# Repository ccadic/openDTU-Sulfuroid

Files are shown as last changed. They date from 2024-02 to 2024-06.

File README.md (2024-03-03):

# openDTU-Sulfuroid

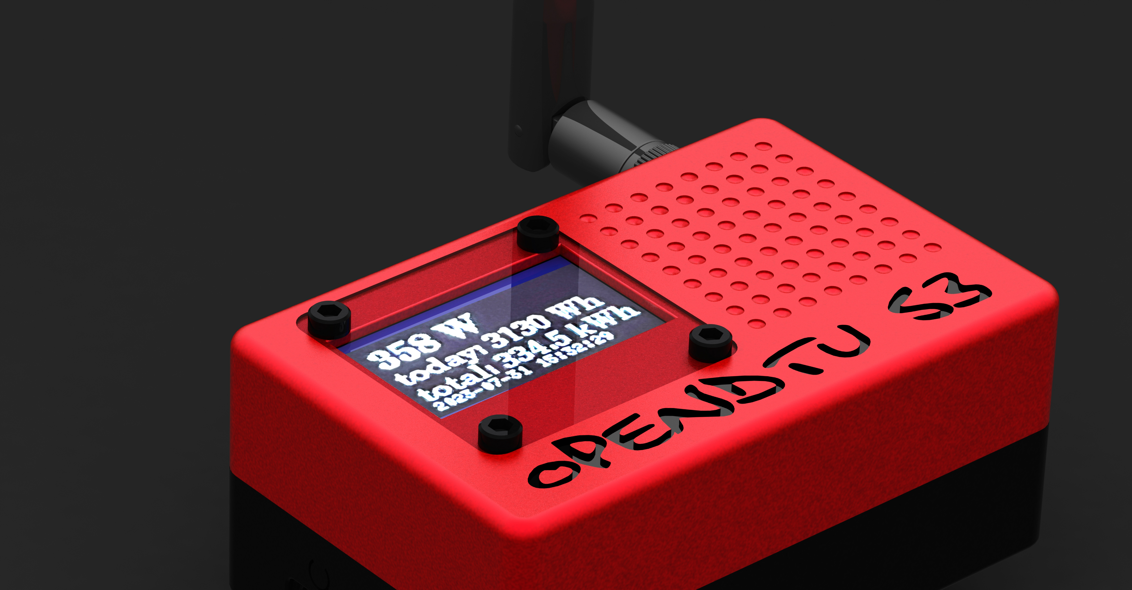
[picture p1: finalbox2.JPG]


Derived from :https://www.opendtu.solar/ 
The pcb is for sale on : https://www.tindie.com/products/electronictrik/esp32s3-opendtu-solar-monitoring-tool/

**Introducing the revolutionary OpenDTU Module: The Future of Solar Energy Management!**

In a world where sustainable energy is not just an option but a necessity, the OpenDTU Module stands as a beacon of innovation and efficiency. Designed with precision and crafted for excellence, this cutting-edge Printed Circuit Board (PCB) is your ultimate gateway to optimizing solar energy production.

The OpenDTU Module revolutionizes the way we interact with solar micro-inverters. Its state-of-the-art design allows for seamless querying of solar micro-inverters, providing you with real-time insights into your energy production. This isn't just about monitoring; it's about maximizing efficiency, reducing costs, and stepping into a future where your solar energy system is smarter and more responsive than ever before.

**Key Features:**

- **Real-Time Monitoring**: Instant access to your energy production data. Watch your energy yield as it happens and make informed decisions on the fly.
- **Universal Compatibility**: Designed to communicate effortlessly with a wide range of solar micro-inverters. The OpenDTU Module speaks the language of your devices.
- **Advanced Analytics**: Not just numbers, but insights. Understand your energy patterns, predict future production, and identify areas for improvement.
- **User-Friendly Interface**: Whether you're a tech wizard or a beginner, the OpenDTU Module offers a simple, intuitive interface for everyone.
- **Robust Design**: Built to last. With its durable components and meticulous design, the OpenDTU Module withstands the test of time and weather.
- **Open Source Freedom**: Unleash the power of community-driven innovation. Customize, enhance, and share your improvements with an ever-growing network of users and developers.
- **Eco-Friendly Operation**: Embrace sustainability not just in energy production but in management too. The OpenDTU Module is designed with eco-conscious materials and processes.

Imagine a world where your solar energy system is not just a part of your home, but a smart, interactive partner in your quest for a sustainable future. The OpenDTU Module brings that world to your doorstep.

Perfect for homeowners, businesses, and solar enthusiasts alike, the OpenDTU Module is more than a PCB; it's a commitment to a brighter, greener planet. Embrace the future of solar energy management today and transform the way you power your world.

Welcome to the era of intelligent solar energy. Welcome to the OpenDTU Module.

Config File for the openDTU PCB

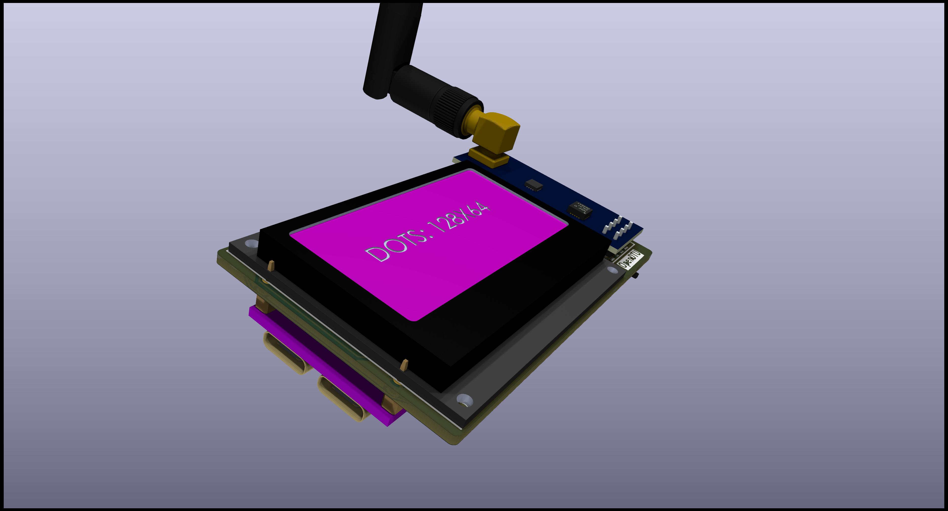
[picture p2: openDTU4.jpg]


Radio modules: https://www.amazon.fr/gp/product/B07VQ838KT/ref=ppx_yo_dt_b_asin_title_o02_s00?ie=UTF8&psc=1
ESP31S3 Long Sev board: https://fr.aliexpress.com/item/1005004642646719.html
Display: https://www.aliexpress.com/item/1005005921902141.html

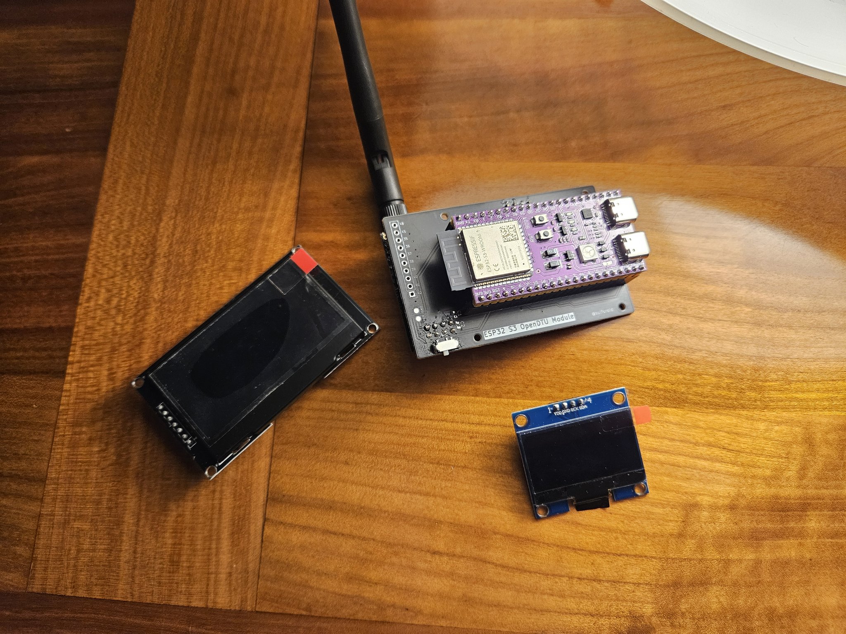
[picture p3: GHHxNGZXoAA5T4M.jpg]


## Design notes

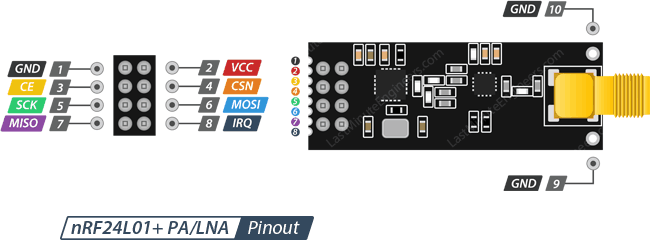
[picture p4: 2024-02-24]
Pinout-nRF24L01-PA-LNA-External-Antenna-Wireless-Transceiver-Module.png

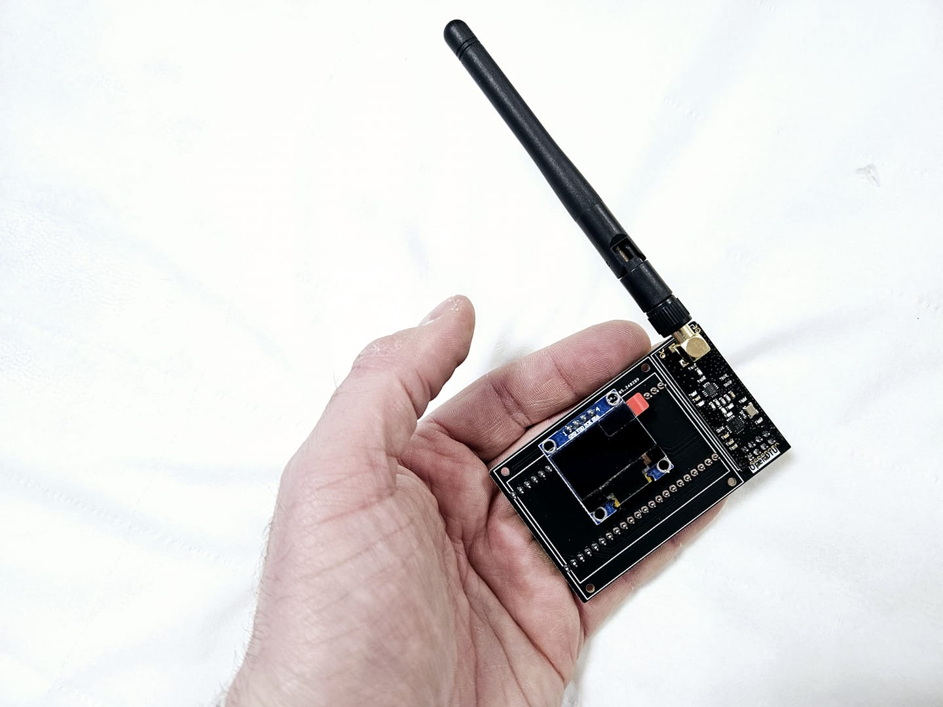
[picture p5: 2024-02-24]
424889018_10231989691474830_318413052973349960_n.jpg

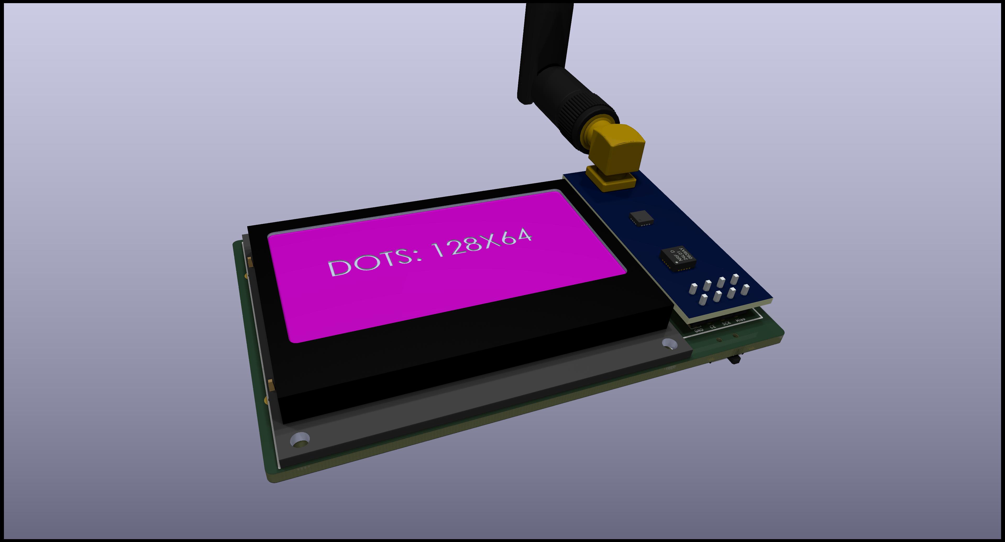
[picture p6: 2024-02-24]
openDTU2.jpg

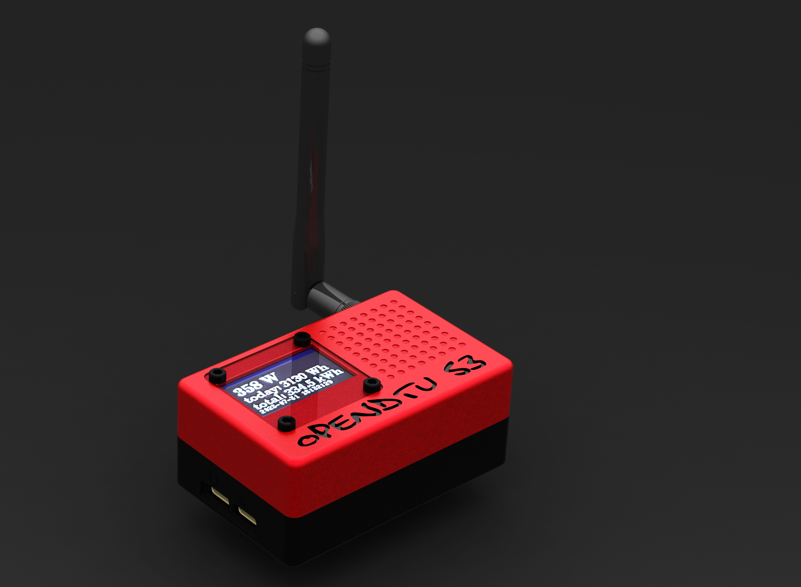
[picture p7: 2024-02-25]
finalbox.JPG

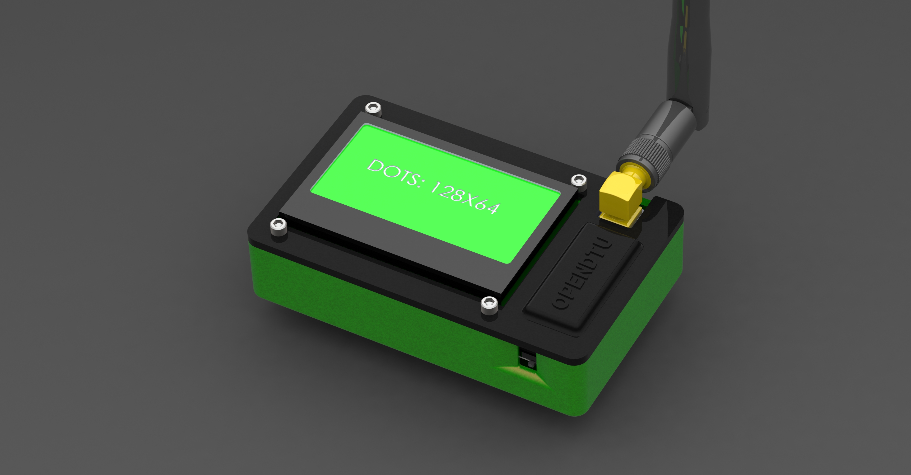
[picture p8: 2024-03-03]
openDTUBIG3.JPG

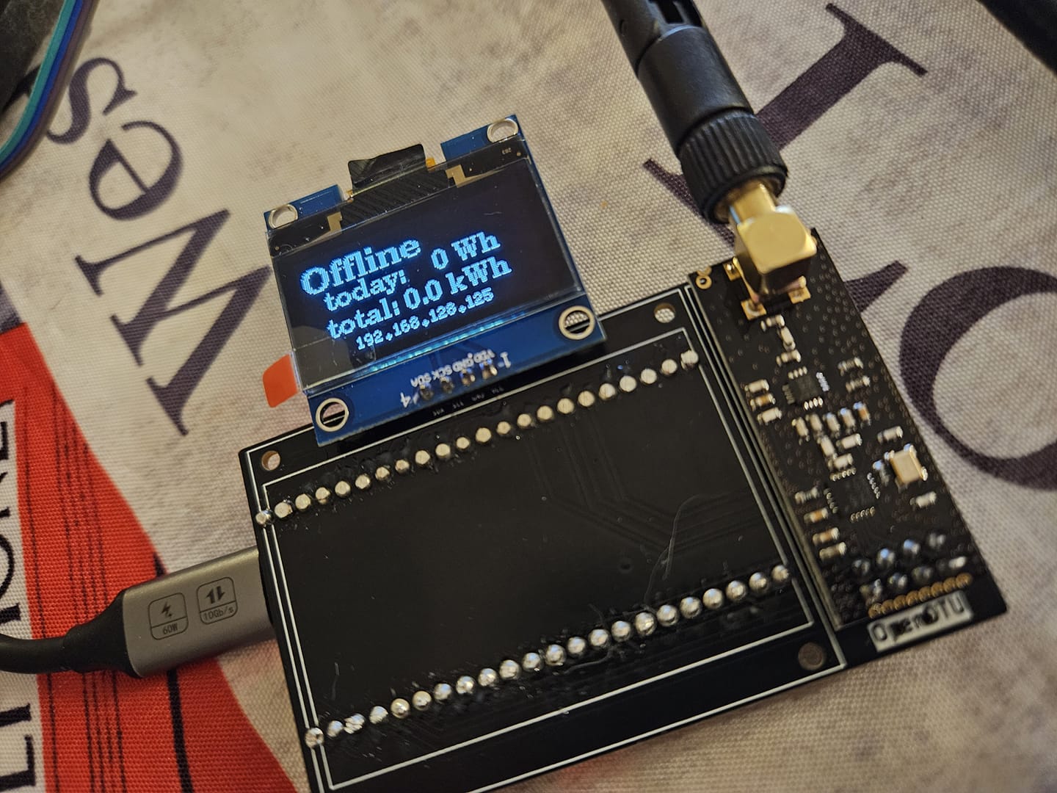
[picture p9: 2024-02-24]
428485526_10231997505990188_1241992412486224182_n.jpg

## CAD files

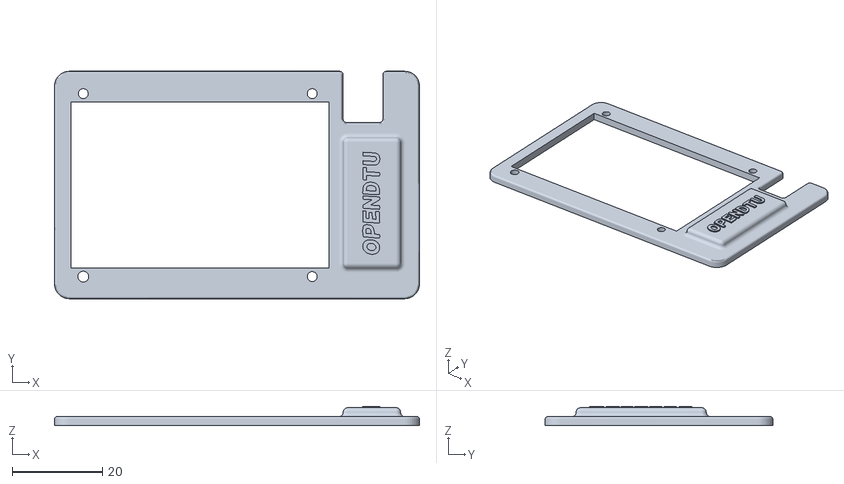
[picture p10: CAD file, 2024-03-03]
3Dfile3/plaqueplexy.STL
81.0 x 50.5 x 4.30

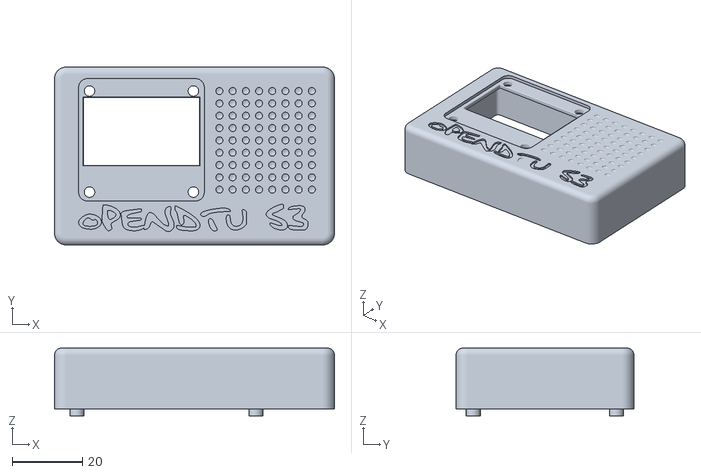
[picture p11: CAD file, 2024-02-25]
3Dfiles/superiorBox.STL
79.5 x 50.5 x 19.3

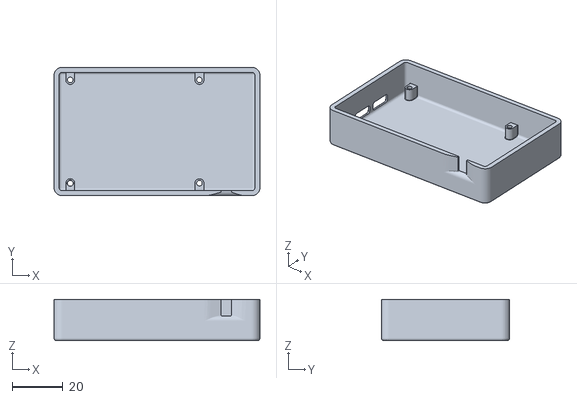
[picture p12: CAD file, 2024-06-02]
3Dfiles2/InferiorBox.STL
81.0 x 50.5 x 16.2

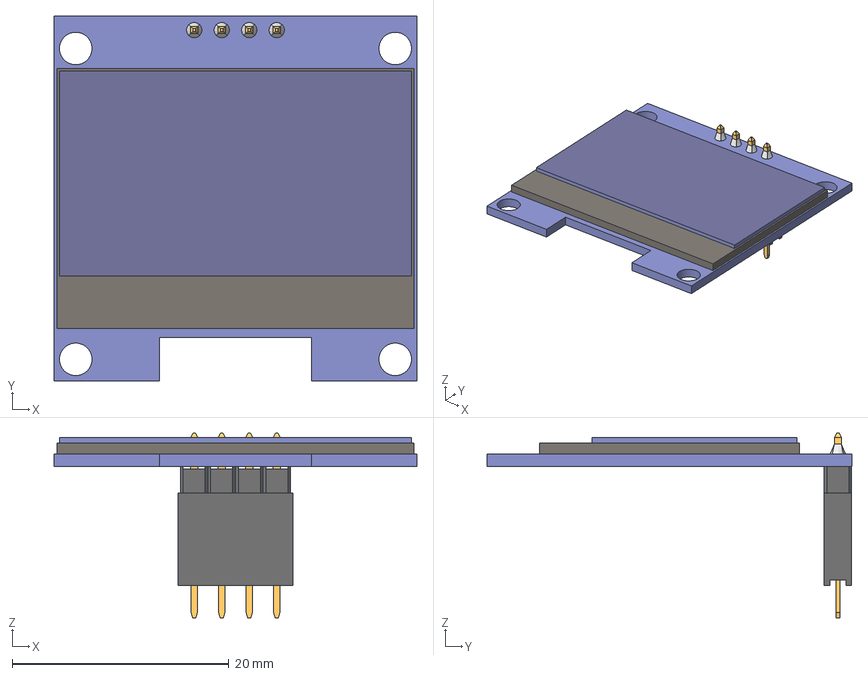
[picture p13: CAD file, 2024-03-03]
OLED I2C 1.3 Inch Display v16.step
33.5 x 33.7 x 17.0 mm
PIN HEADER MALE 2.54MM P4
PIN HEADER FAMALE 2.54MM P4
4 lü Lehim v2

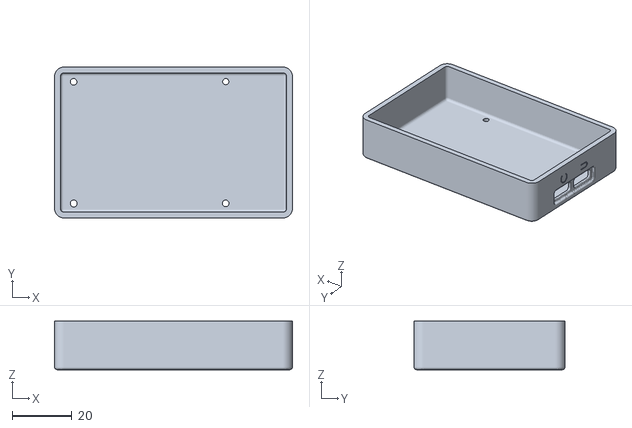
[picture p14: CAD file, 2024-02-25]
3Dfiles/InferiorBox.STL
79.5 x 50.5 x 16.2

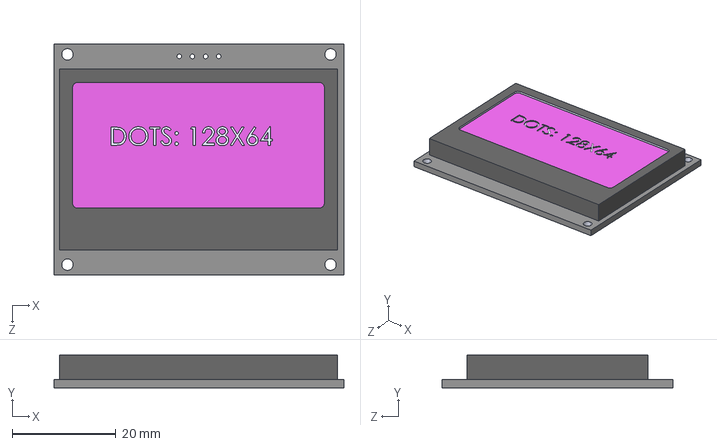
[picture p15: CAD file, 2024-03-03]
LCD-GM12864-59N.STEP
56.0 x 6.30 x 44.6 mm

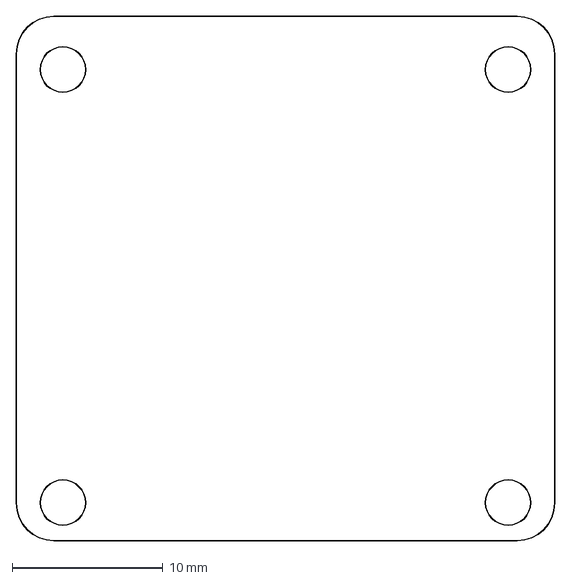
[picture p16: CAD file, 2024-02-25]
3Dfiles/frontglass-laser.DXF
35.7 x 34.8 mm

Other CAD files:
3Dfile3/InferiorBox3.STL
3Dfile3/plaqueplexy.DXF

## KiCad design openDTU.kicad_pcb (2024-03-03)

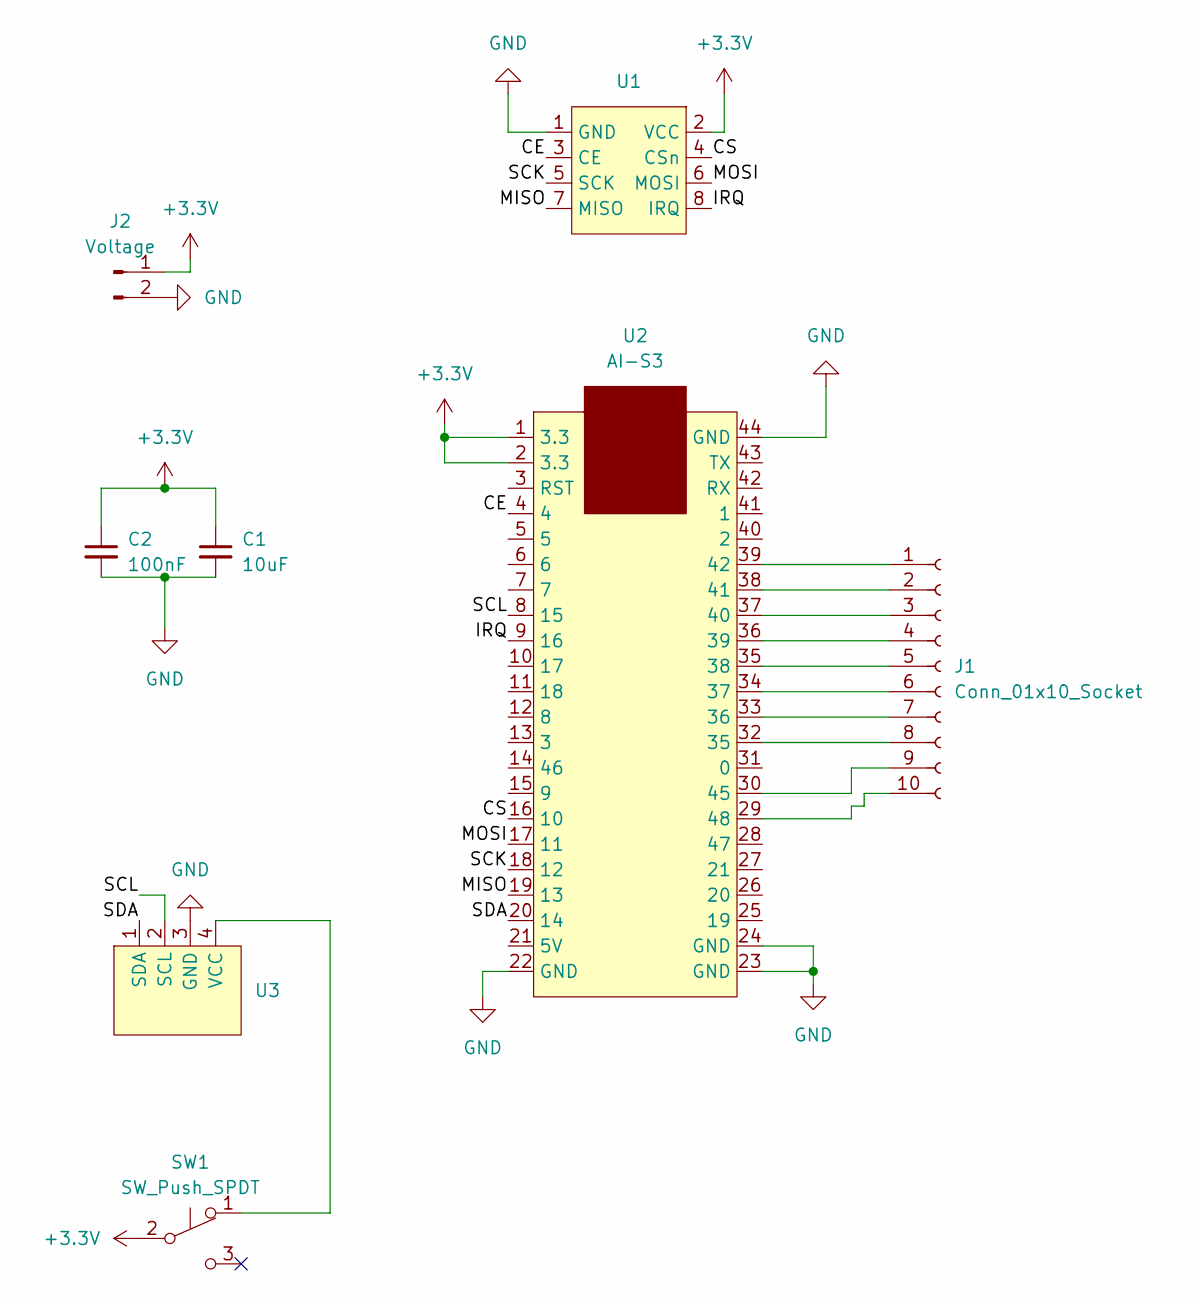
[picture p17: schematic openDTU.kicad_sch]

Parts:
C1: 10uF; C_0603_1608Metric
C2: 100nF; C_0603_1608Metric
J1: Conn_01x10_Socket; PinHeader_1x10_P2.54mm_Vertical
J2: Voltage; 2padsfree
SW1: SW_Push_SPDT; SW_SPDT_PCM12
U1: NRF24l01
U2: AI-S3
U3: GM12864-59N

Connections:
+3.3V: C1.1, C2.1, J2.1, SW1.2 (B), U1.2 (VCC), U2.1 (3.3), U2.2 (3.3)
/CE: U1.3 (CE), U2.4
/CS: U1.4 (CSn), U2.16 (10)
/IRQ: U1.8 (IRQ), U2.9 (16)
/MISO: U1.7 (MISO), U2.19 (13)
/MOSI: U1.6 (MOSI), U2.17 (11)
/SCK: U1.5 (SCK), U2.18 (12)
/SCL: U2.8 (15), U3.2 (SCL)
/SDA: U2.20 (14), U3.1 (SDA)
GND: C1.2, C2.2, J2.2, U1.1 (GND), U2.22 (GND), U2.23 (GND), U2.24 (GND), U2.44 (GND), U3.3 (GND)
unnamed: J1.1, U2.39 (42)
unnamed: J1.2, U2.38 (41)
unnamed: J1.3, U2.37 (40)
unnamed: J1.4, U2.36 (39)
unnamed: J1.5, U2.35 (38)
unnamed: J1.6, U2.34 (37)
unnamed: J1.7, U2.33 (36)
unnamed: J1.8, U2.32 (35)
unnamed: J1.9, U2.30 (45)
unnamed: J1.10, U2.29 (48)
unnamed: SW1.1 (A), U3.4 (VCC)

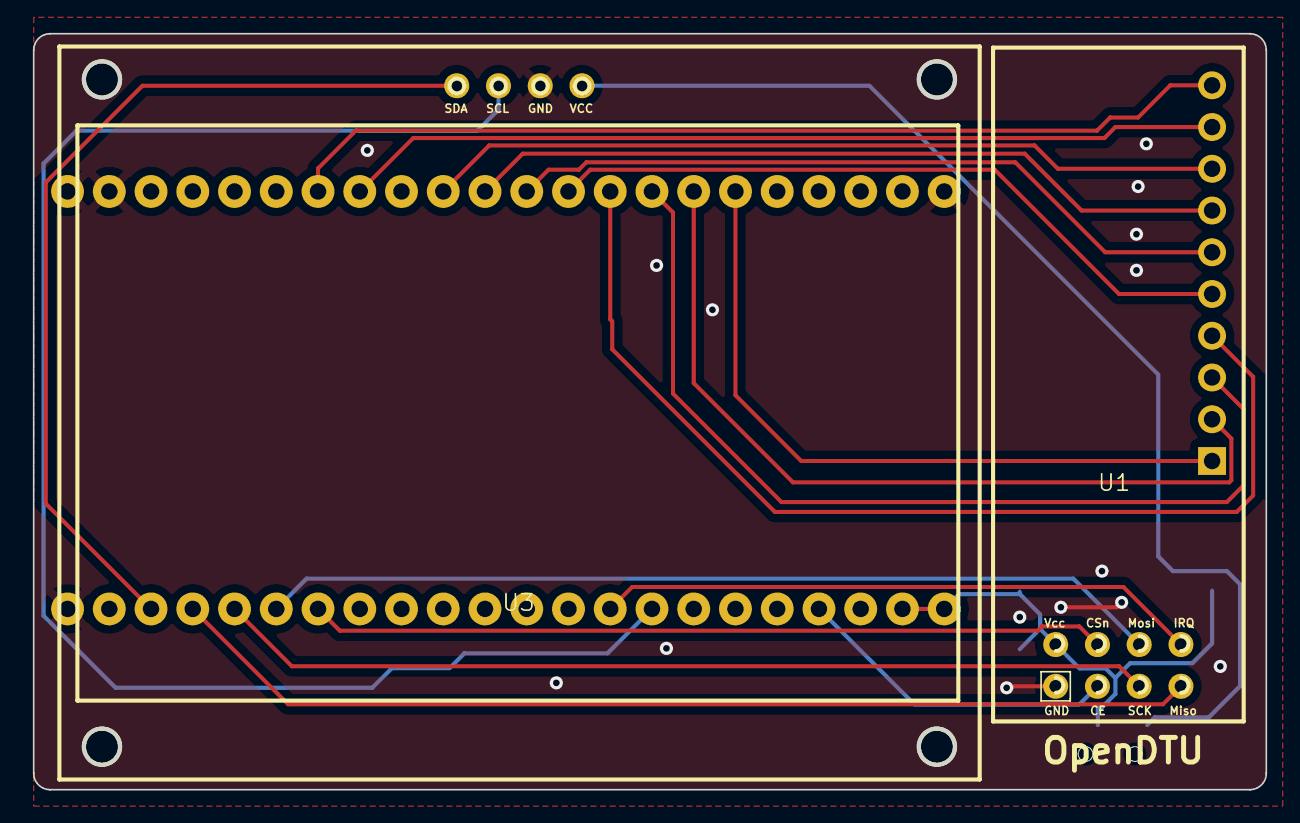
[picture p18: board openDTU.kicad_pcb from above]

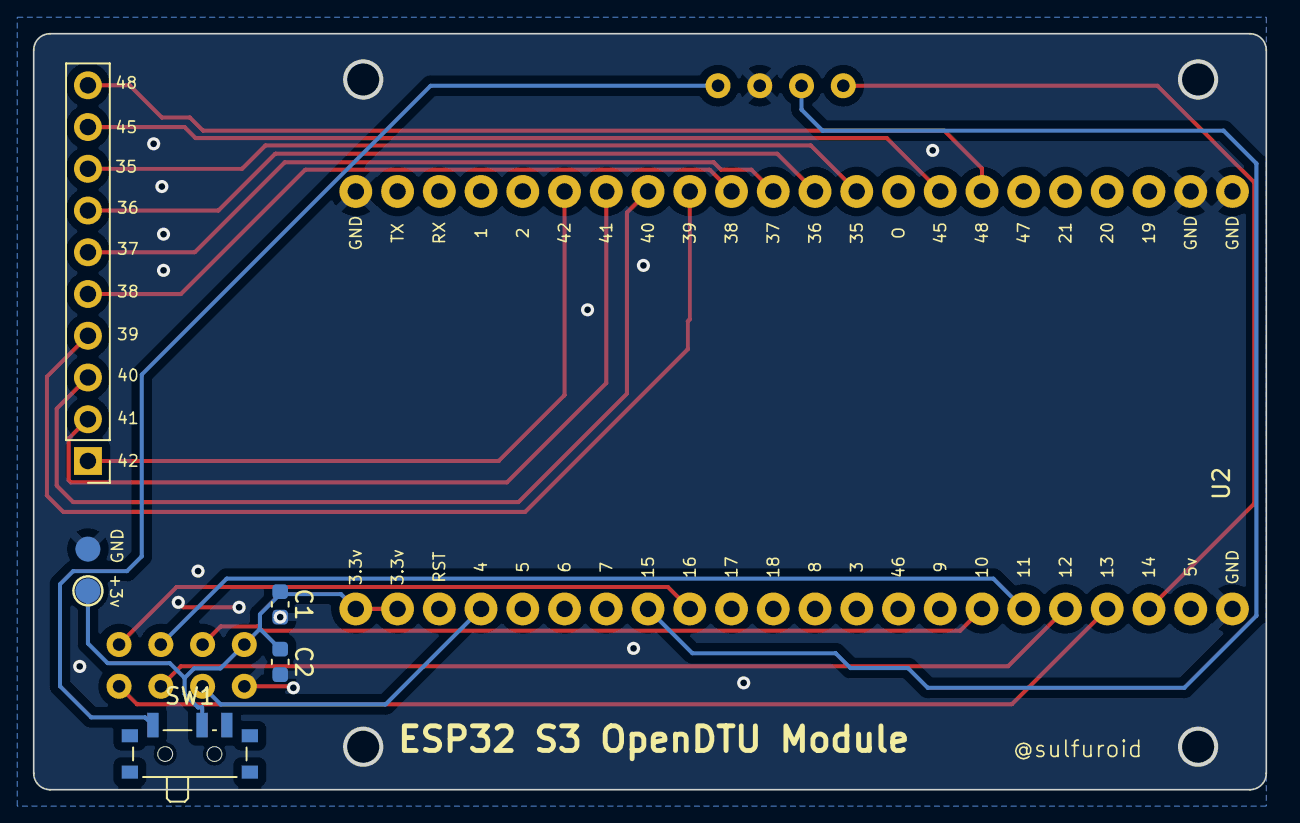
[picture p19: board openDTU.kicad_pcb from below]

Board: 2 copper layers, 75.0 x 46.0 mm, 8 parts (6 on the bottom side), 21 nets.

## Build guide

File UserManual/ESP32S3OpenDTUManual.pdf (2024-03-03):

## OpenDTU ESP32S3 MODULE PCB

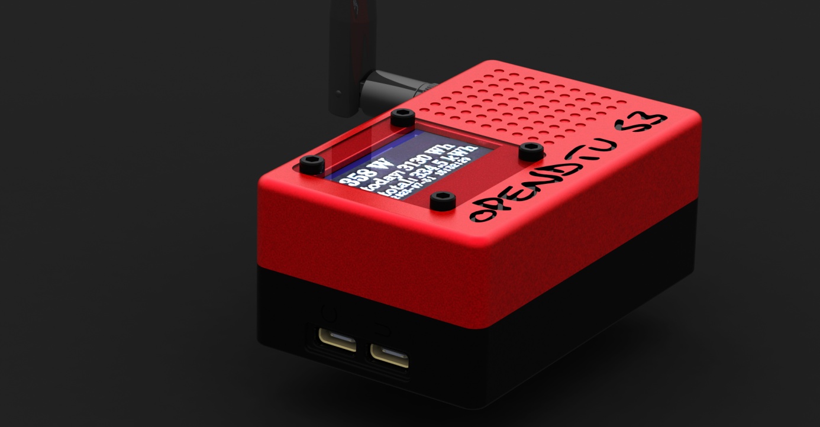
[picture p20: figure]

### USER AND SETUP MANUAL

By @sulfuroid

Description of the PCB Board and OpenDTU

OpenDTU is a free, open-source application designed for communication with Hoymiles solar inverters and several others inverters (list at the bottom), offering an alternative to the proprietary DTUs that upload data to the s-Miles cloud.

Please be aware that each inverter can only be paired with a single DTU. Attempting to connect an inverter with more than one DTU can cause unexpected behavior.

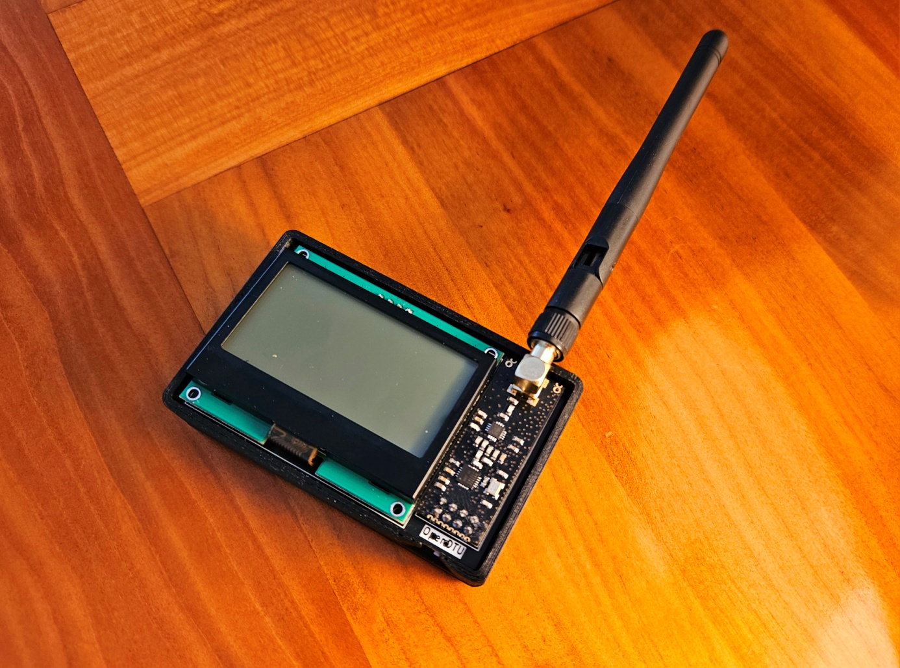
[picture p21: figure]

Key Features:

- Retrieves real-time data directly from the inverter.
- Accesses the inverter's internal event history.
- Displays detailed inverter information, including firmware and hardware versions, firmware release date, and hardware revision.
- Enables viewing and adjusting the inverter's operational limits.
- Allows for inspection and modification of grid profile settings.
- Includes a feature to power the inverter off and on.
- Compatible with up to 10 inverters simultaneously.
- Features MQTT compatibility, including secure TLS connection.
- Supports MQTT Auto Discovery for seamless integration with Home Assistant.
- Offers a user-friendly web application for data visualization.
- Facilitates firmware updates through the web interface.
- Includes time zone adjustment capability.
- Provides Ethernet connectivity.

- Features a Prometheus API endpoint for metrics (/api/prometheus/metrics).
- Available in English, German, and French for the web interface.
- Supports various display types (SSD1306, SH1106, PCD8544).
- Equipped with status indicator LEDs.
- Allows for easy configuration management, including the ability to export and import settings.
- Features a Dark Theme option for the interface.

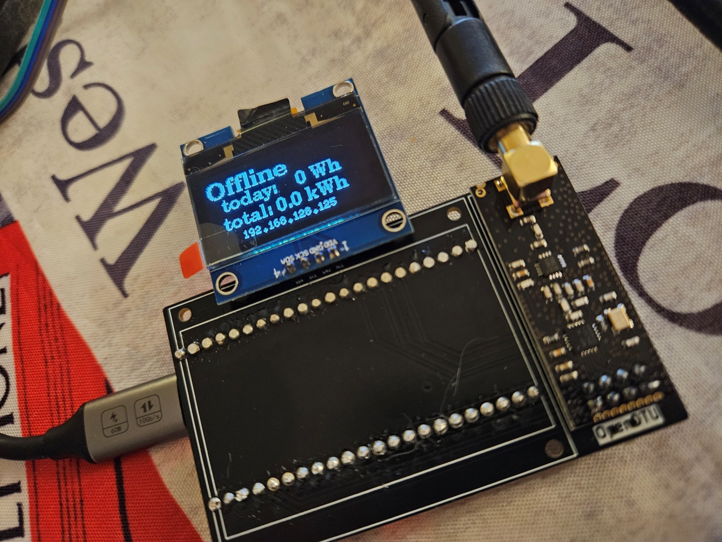
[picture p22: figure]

Components list and where to get them

Source for the GM12864-59N Display

https://www.aliexpress.com/item/1005004237282931.html

Source for the NRF24L01+ Radio chip

https://fr.aliexpress.com/item/1005004941530728.html

Source for OpenDTU Software

https://github.com/tbnobody/OpenDTU

Source for the ESP32S3 DEV BOARD (S3 N16R8)

https://fr.aliexpress.com/item/1005006051177409.html

How to flash the software onto the ESP32S3

Go to https://espressif.github.io/esptool-js/

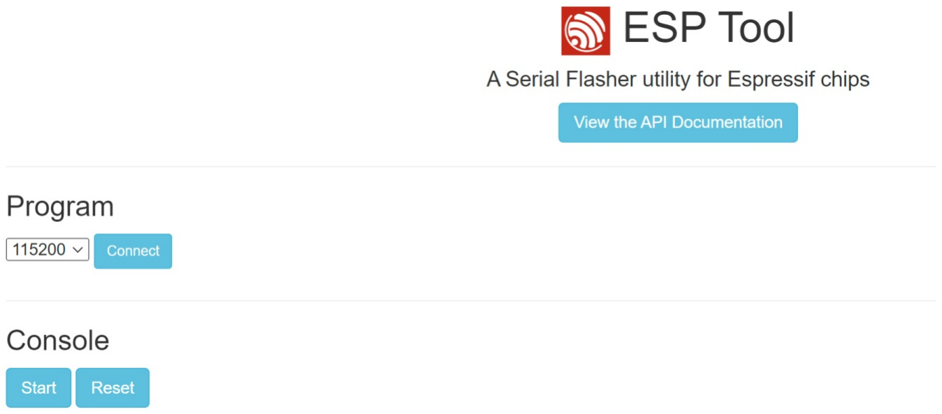
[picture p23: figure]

Plug the ESP32S3 dev module to your computer USB. USB-C plug named « COM » on the ESP32 Dev Board.

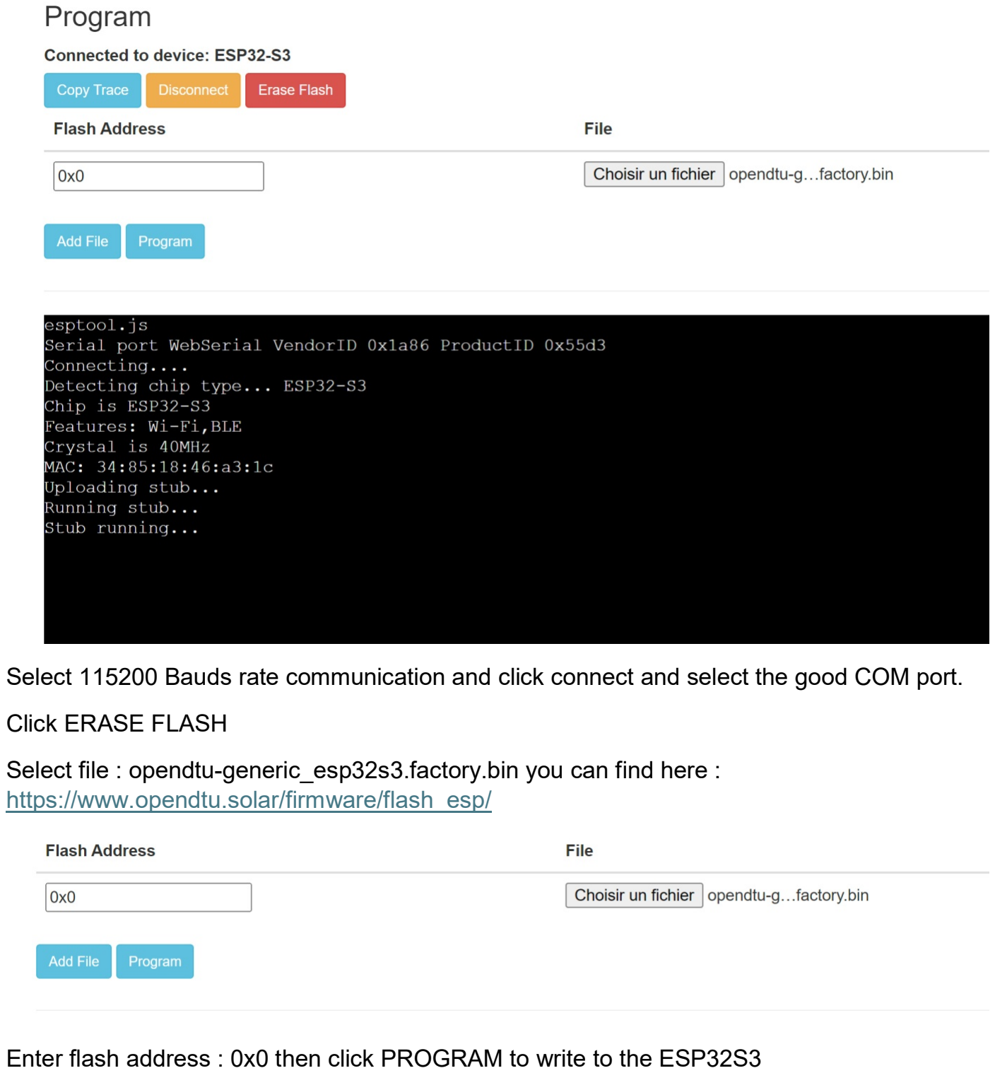
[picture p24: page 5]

Select 115200 Bauds rate communication and click connect and select the good COM port.

Click ERASE FLASH

Select file : opendtu-generic_esp32s3.factory.bin you can find here : https://www.opendtu.solar/firmware/flash_esp/

Enter flash address : 0x0 then click PROGRAM to write to the ESP32S3

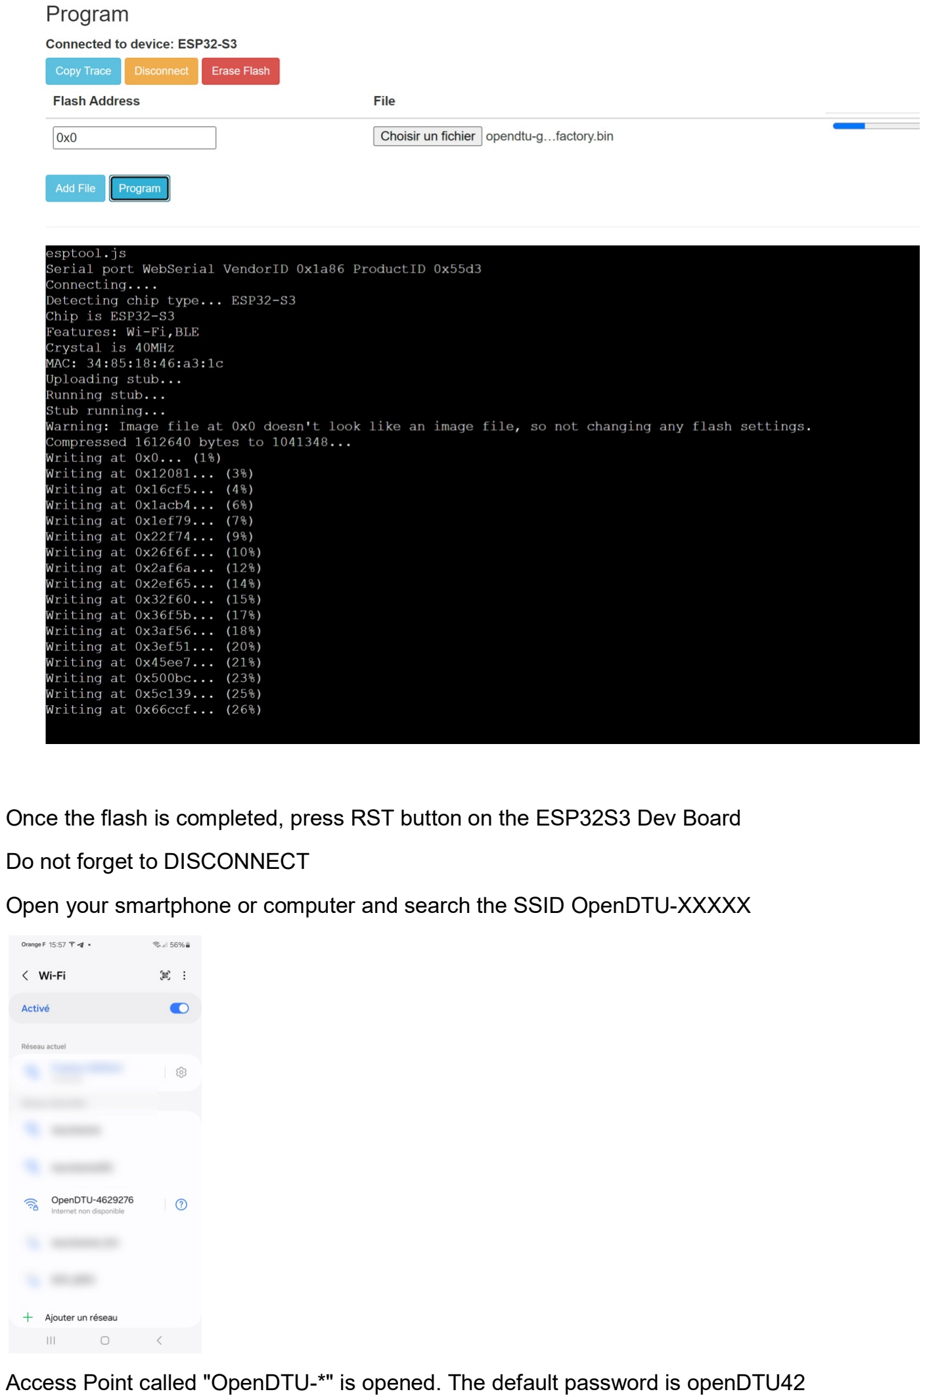
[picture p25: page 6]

Once the flash is completed, press RST button on the ESP32S3 Dev Board

Do not forget to DISCONNECT

Open your smartphone or computer and search the SSID OpenDTU-XXXXX

Access Point called "OpenDTU-*" is opened. The default password is openDTU42

Use http://192.168.4.1 to access the configuration of the device.

Navigate to Settings --> Network Settings and enter your WiFi credentials. The username to access the config menu is "admin" and the password the same as for accessing the Access Point (default: openDTU42) . Once your wifi setting are set , press « SAVE ». More info here : https://www.opendtu.solar/firmware/wifi_setup/

Then use an IP scanner such as : https://www.advanced-ip-scanner.com/fr/ and find the IP of the MODULE on your wifi network. Open your web browser and go to CONFIG
MANAGEMENT (user name : admin , pass : openDTU42) , select pinmapping then select the file « pin_mappingdemo.json » file and click restore.

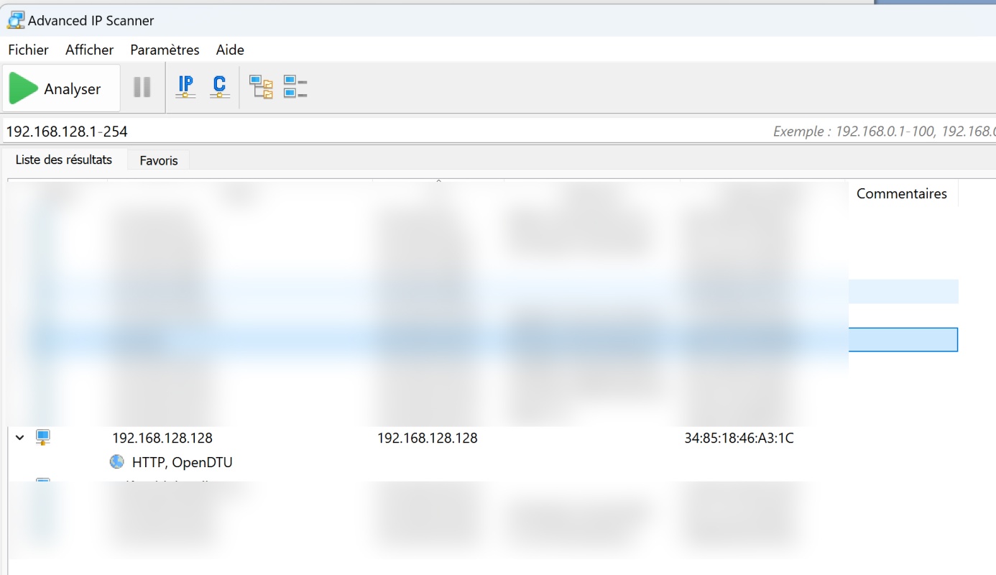
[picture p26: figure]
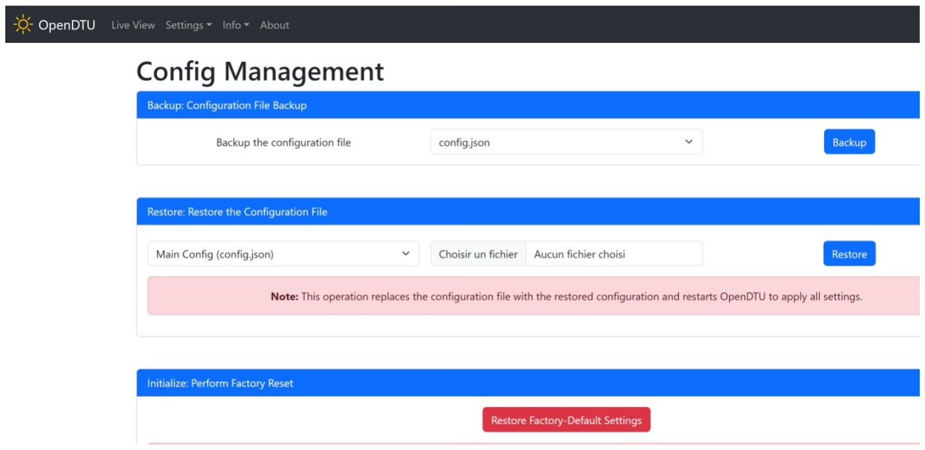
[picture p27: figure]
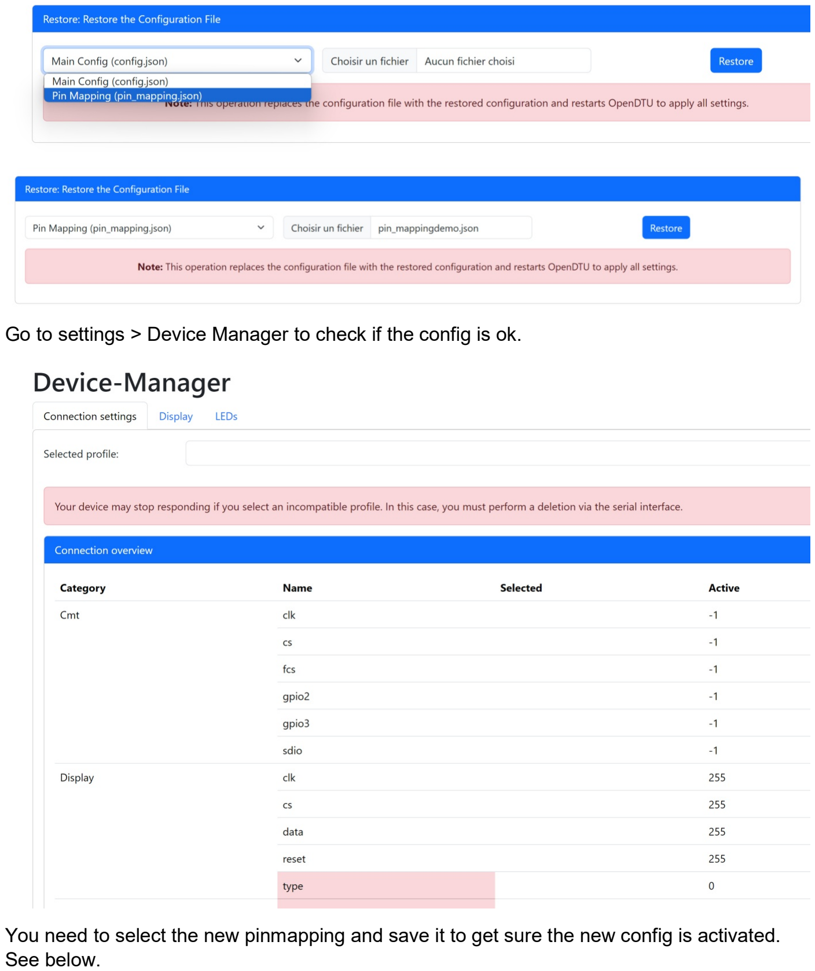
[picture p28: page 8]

Go to settings > Device Manager to check if the config is ok.

You need to select the new pinmapping and save it to get sure the new config is activated. See below.

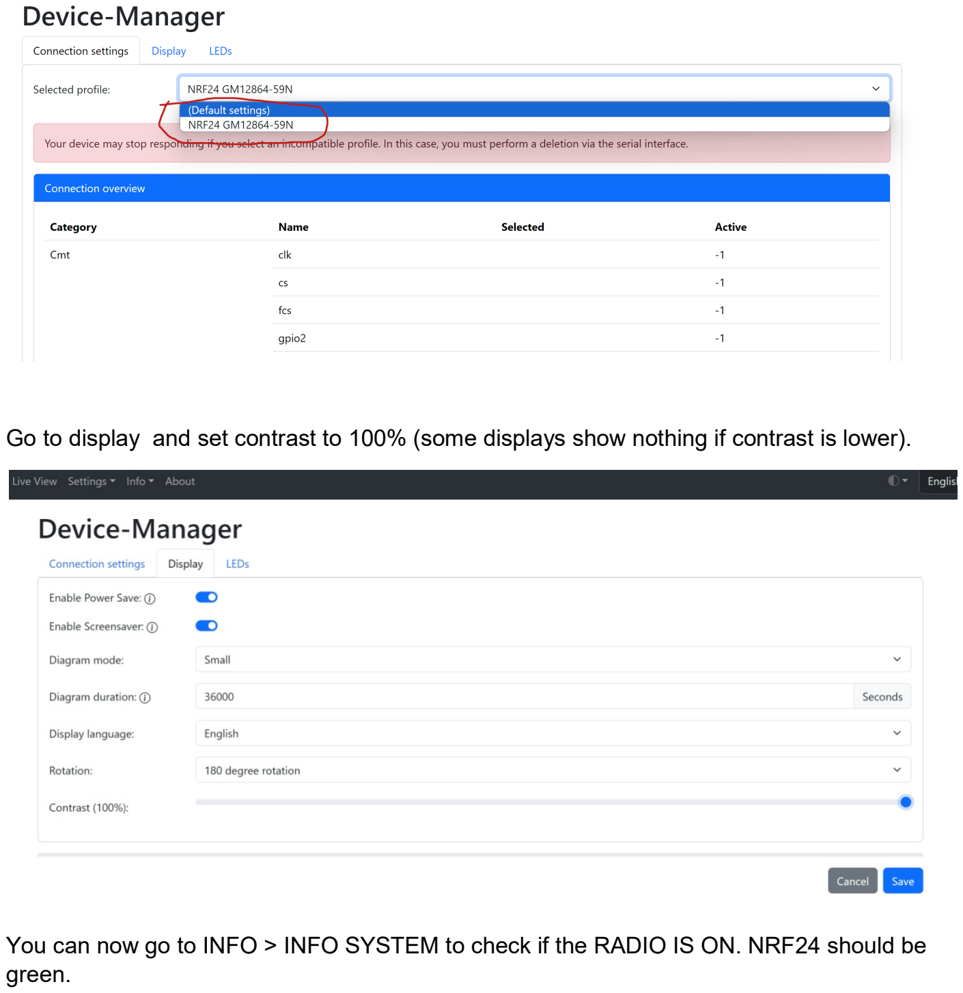
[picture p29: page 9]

Go to display and set contrast to 100% (some displays show nothing if contrast is lower).

You can now go to INFO > INFO SYSTEM to check if the RADIO IS ON. NRF24 should be green.

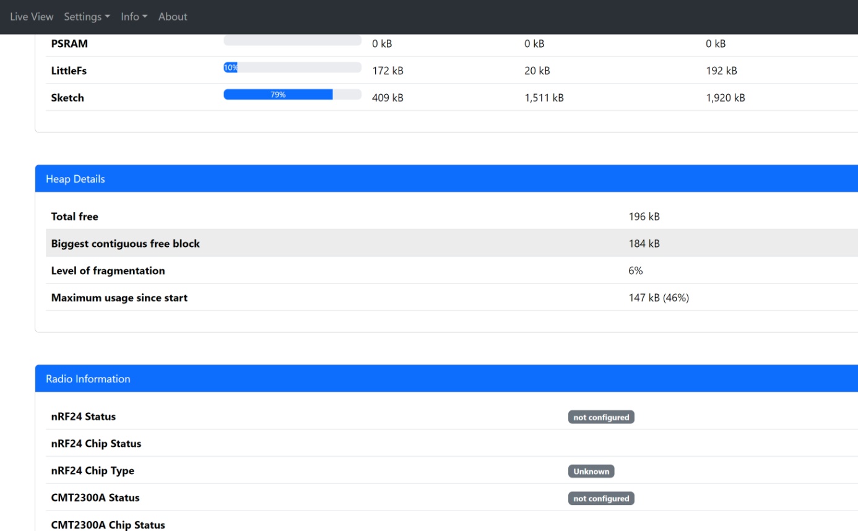
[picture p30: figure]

You can now follow the instruction of https://www.opendtu.solar/firmware/configuration/inverter_settings/ to add inverters to the config.

Known Compatible inverters
- Hoymiles HM-300-1T
- Hoymiles HM-350-1T
- Hoymiles HM-400-1T
- Hoymiles HM-600-2T
- Hoymiles HM-700-2T
- Hoymiles HM-800-2T
- Hoymiles HM-1000-4T
- Hoymiles HM-1200-4T
- Hoymiles HM-1500-4T
- Solenso SOL-H350
- Solenso SOL-H400
- Solenso SOL-H800
- TSUN TSOL-M350
- TSUN TSOL-M800
- TSUN TSOL-M1600
